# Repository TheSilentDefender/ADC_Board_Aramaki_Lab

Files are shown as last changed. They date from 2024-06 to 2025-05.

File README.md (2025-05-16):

# ADC Hub for pGRAMS
- Has 48 ADC channels and an optional voltage divider can be used for RTDs.
- The ADCs only support a range of 0-5V. Any input outside the range may damage the ADCs on board.
- The board outputs ADC integer values with a 12-bit resolution(0-4095)

## How to build
- Install platform.io on Visual Studio Code. You can also install it manually by following the documenation on [the website](https://platformio.org).
- Open the folder using VSC and wait for platform.io to initialize
- Open the platform.io side panel and click build. This should automatically build with the settings in the configuation file.

## How to flash
- Connect to the board in DFU mode or enter in "d" through serial (press the button on the top while you plug in the board)
- Assuming you followed the instuctions for building, you can click on build and upload which will automatic flash the board and restart it.
- If not you can download the bin file and flash it using dfu-util or any other DFU upgrade tool. For example, `sudo dfu-util -a 0 -i 0 -s 0x08000000:leave -D firmware.bin`.

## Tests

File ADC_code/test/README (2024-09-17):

        
This directory is intended for PlatformIO Test Runner and project tests.

Unit Testing is a software testing method by which individual units of
source code, sets of one or more MCU program modules together with associated
control data, usage procedures, and operating procedures, are tested to
determine whether they are fit for use. Unit testing finds problems early
in the development cycle.

More information about PlatformIO Unit Testing:
- https://docs.platformio.org/en/latest/advanced/unit-testing/index.html

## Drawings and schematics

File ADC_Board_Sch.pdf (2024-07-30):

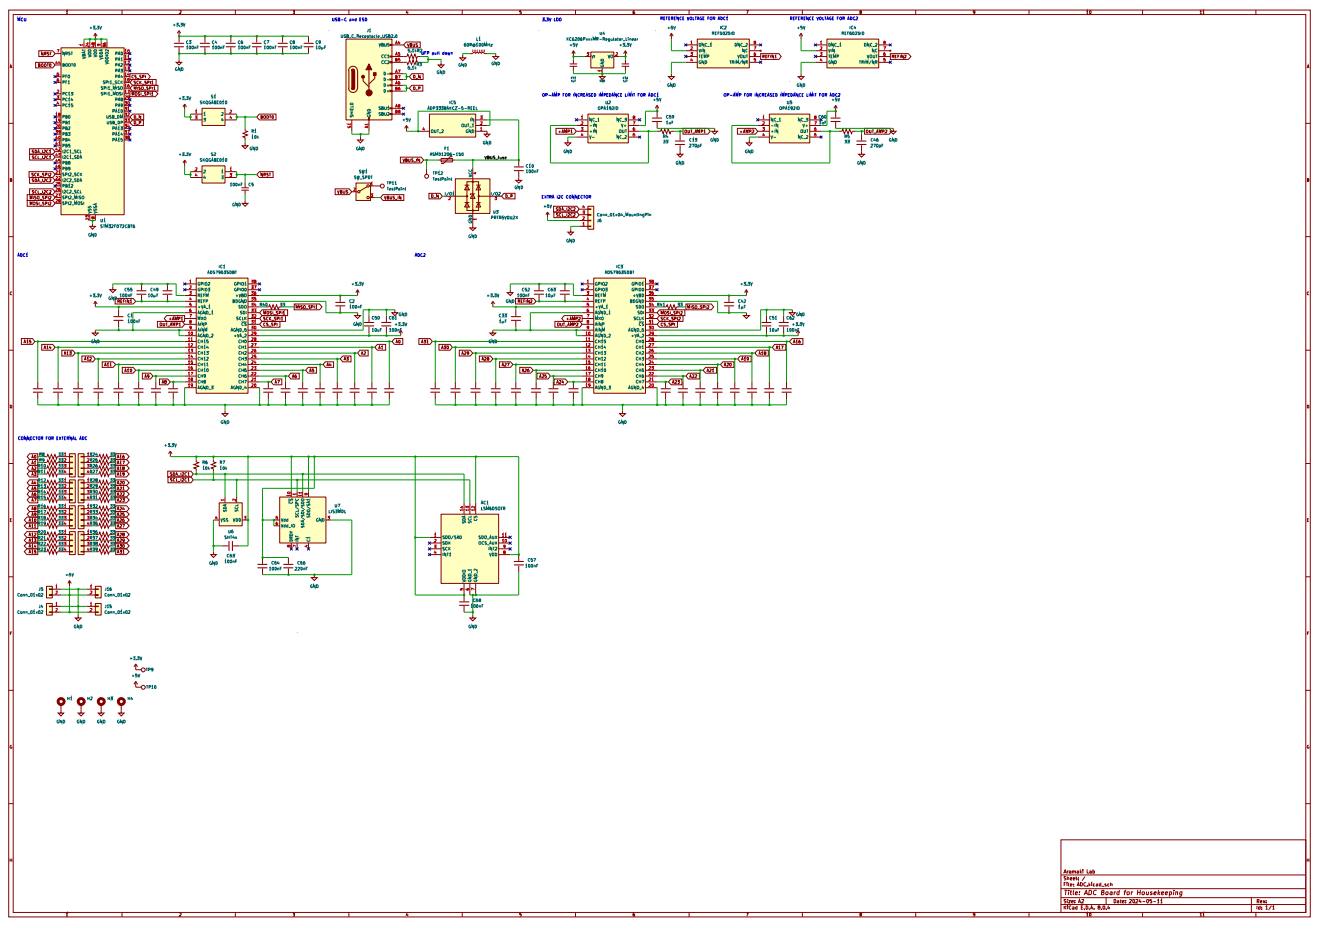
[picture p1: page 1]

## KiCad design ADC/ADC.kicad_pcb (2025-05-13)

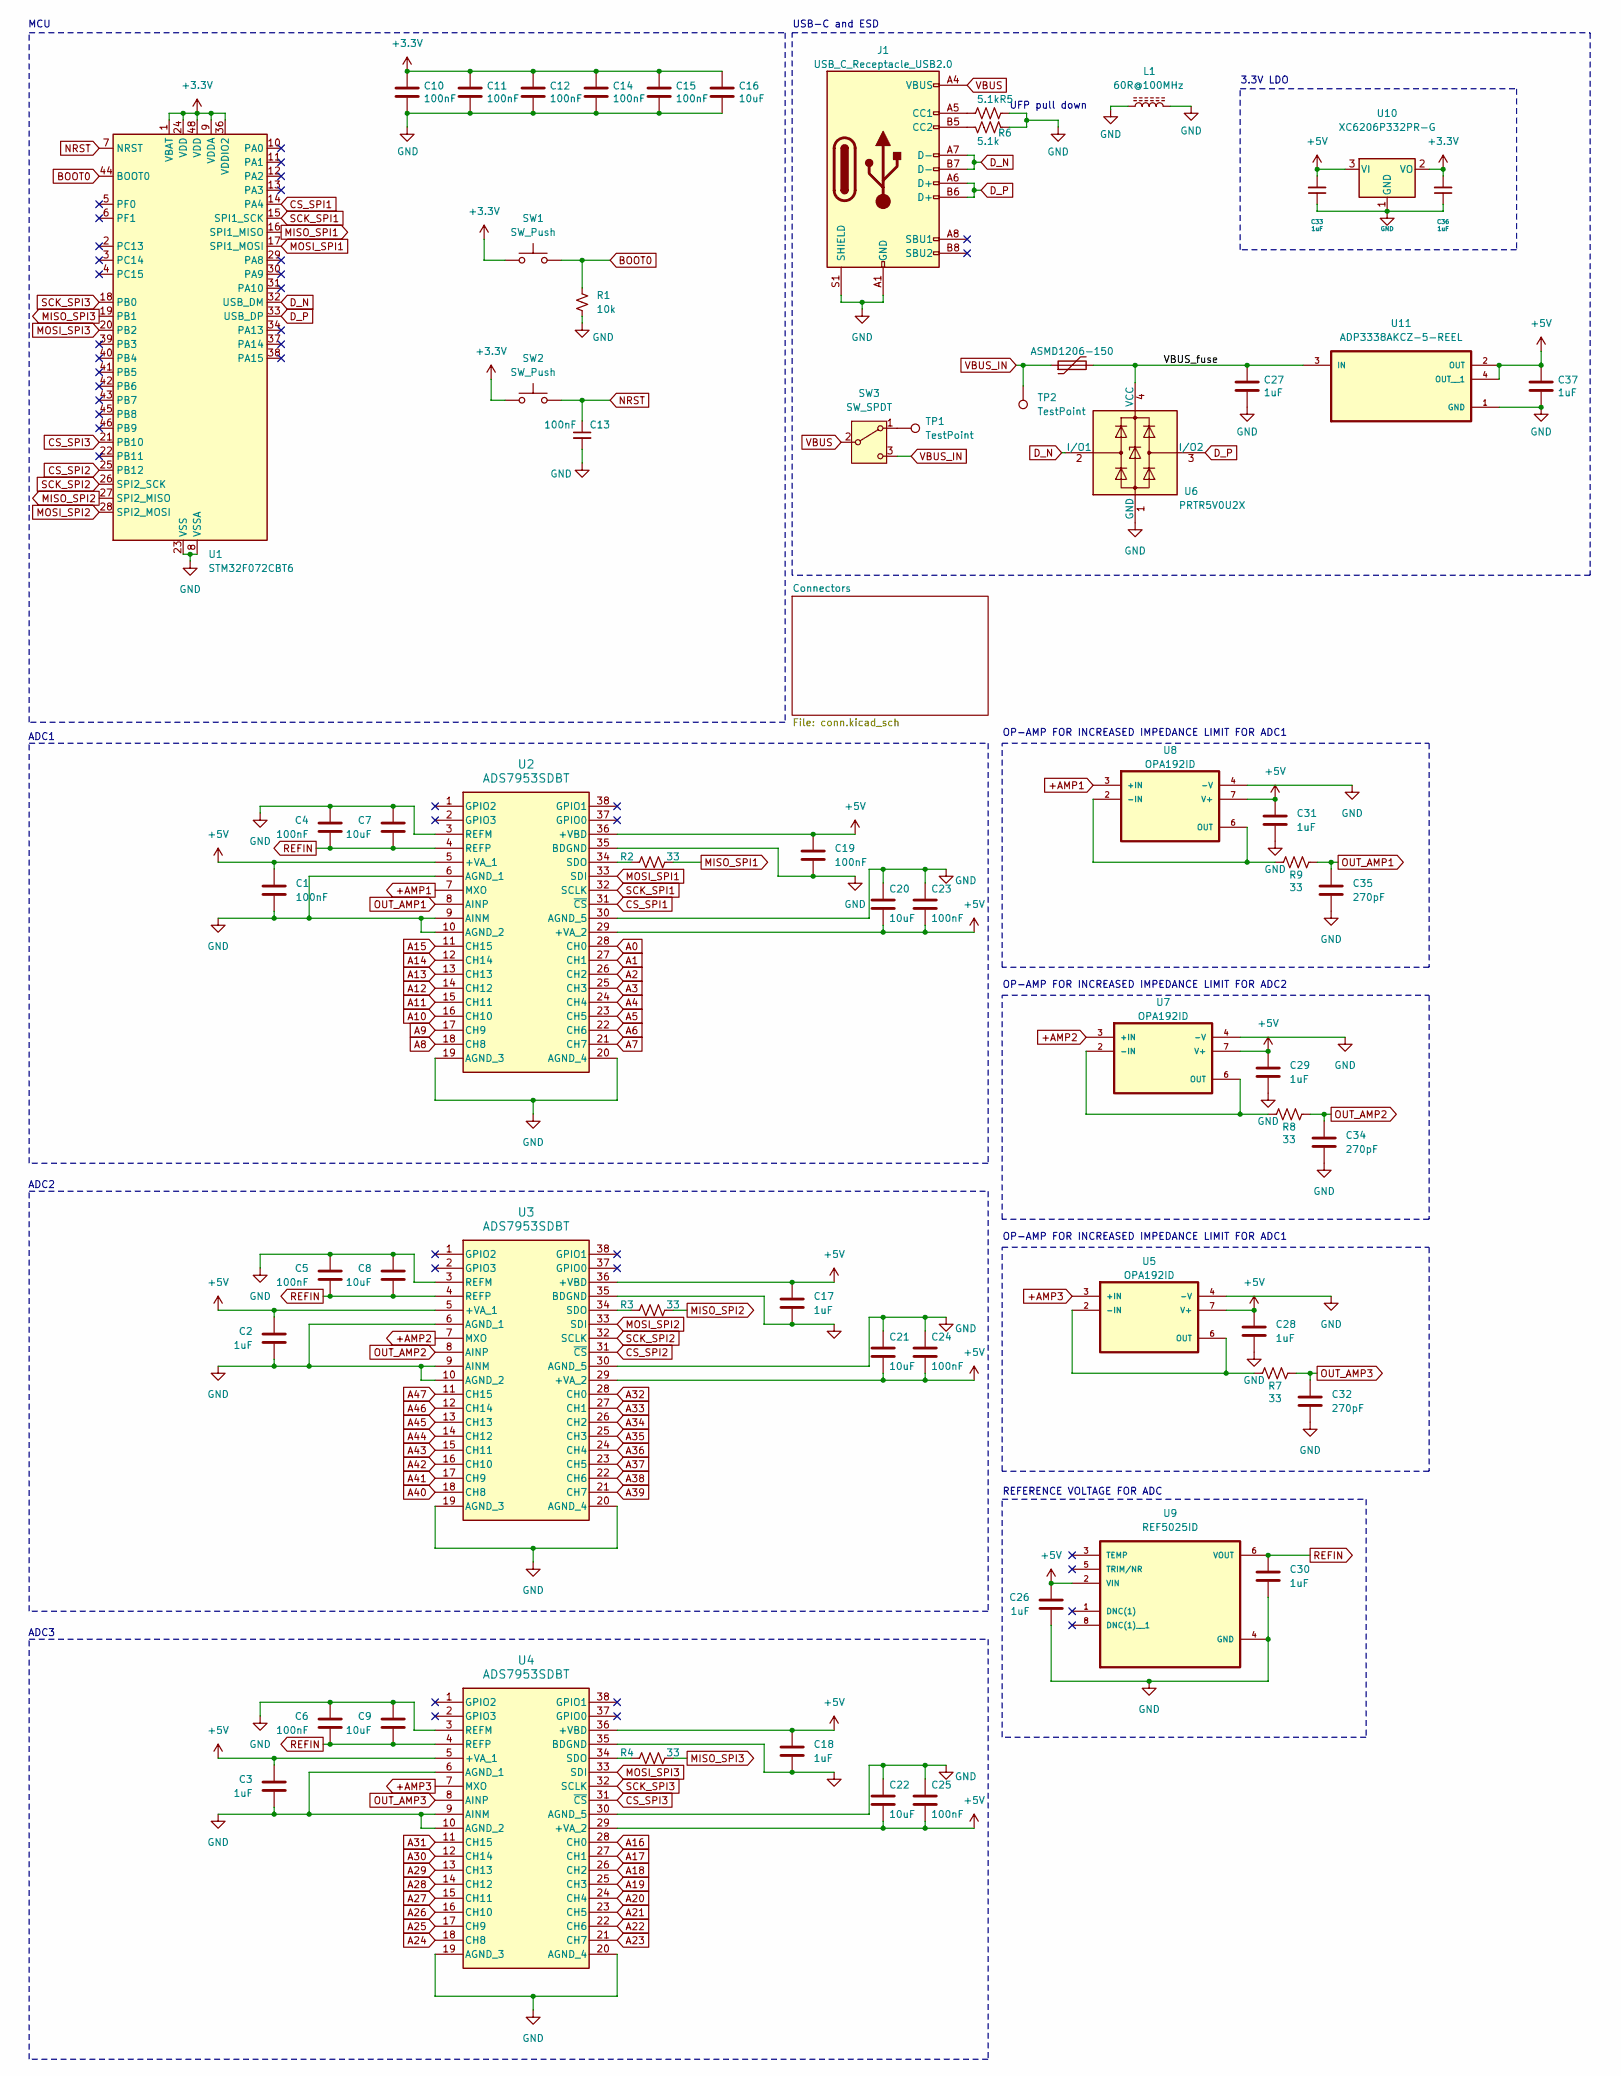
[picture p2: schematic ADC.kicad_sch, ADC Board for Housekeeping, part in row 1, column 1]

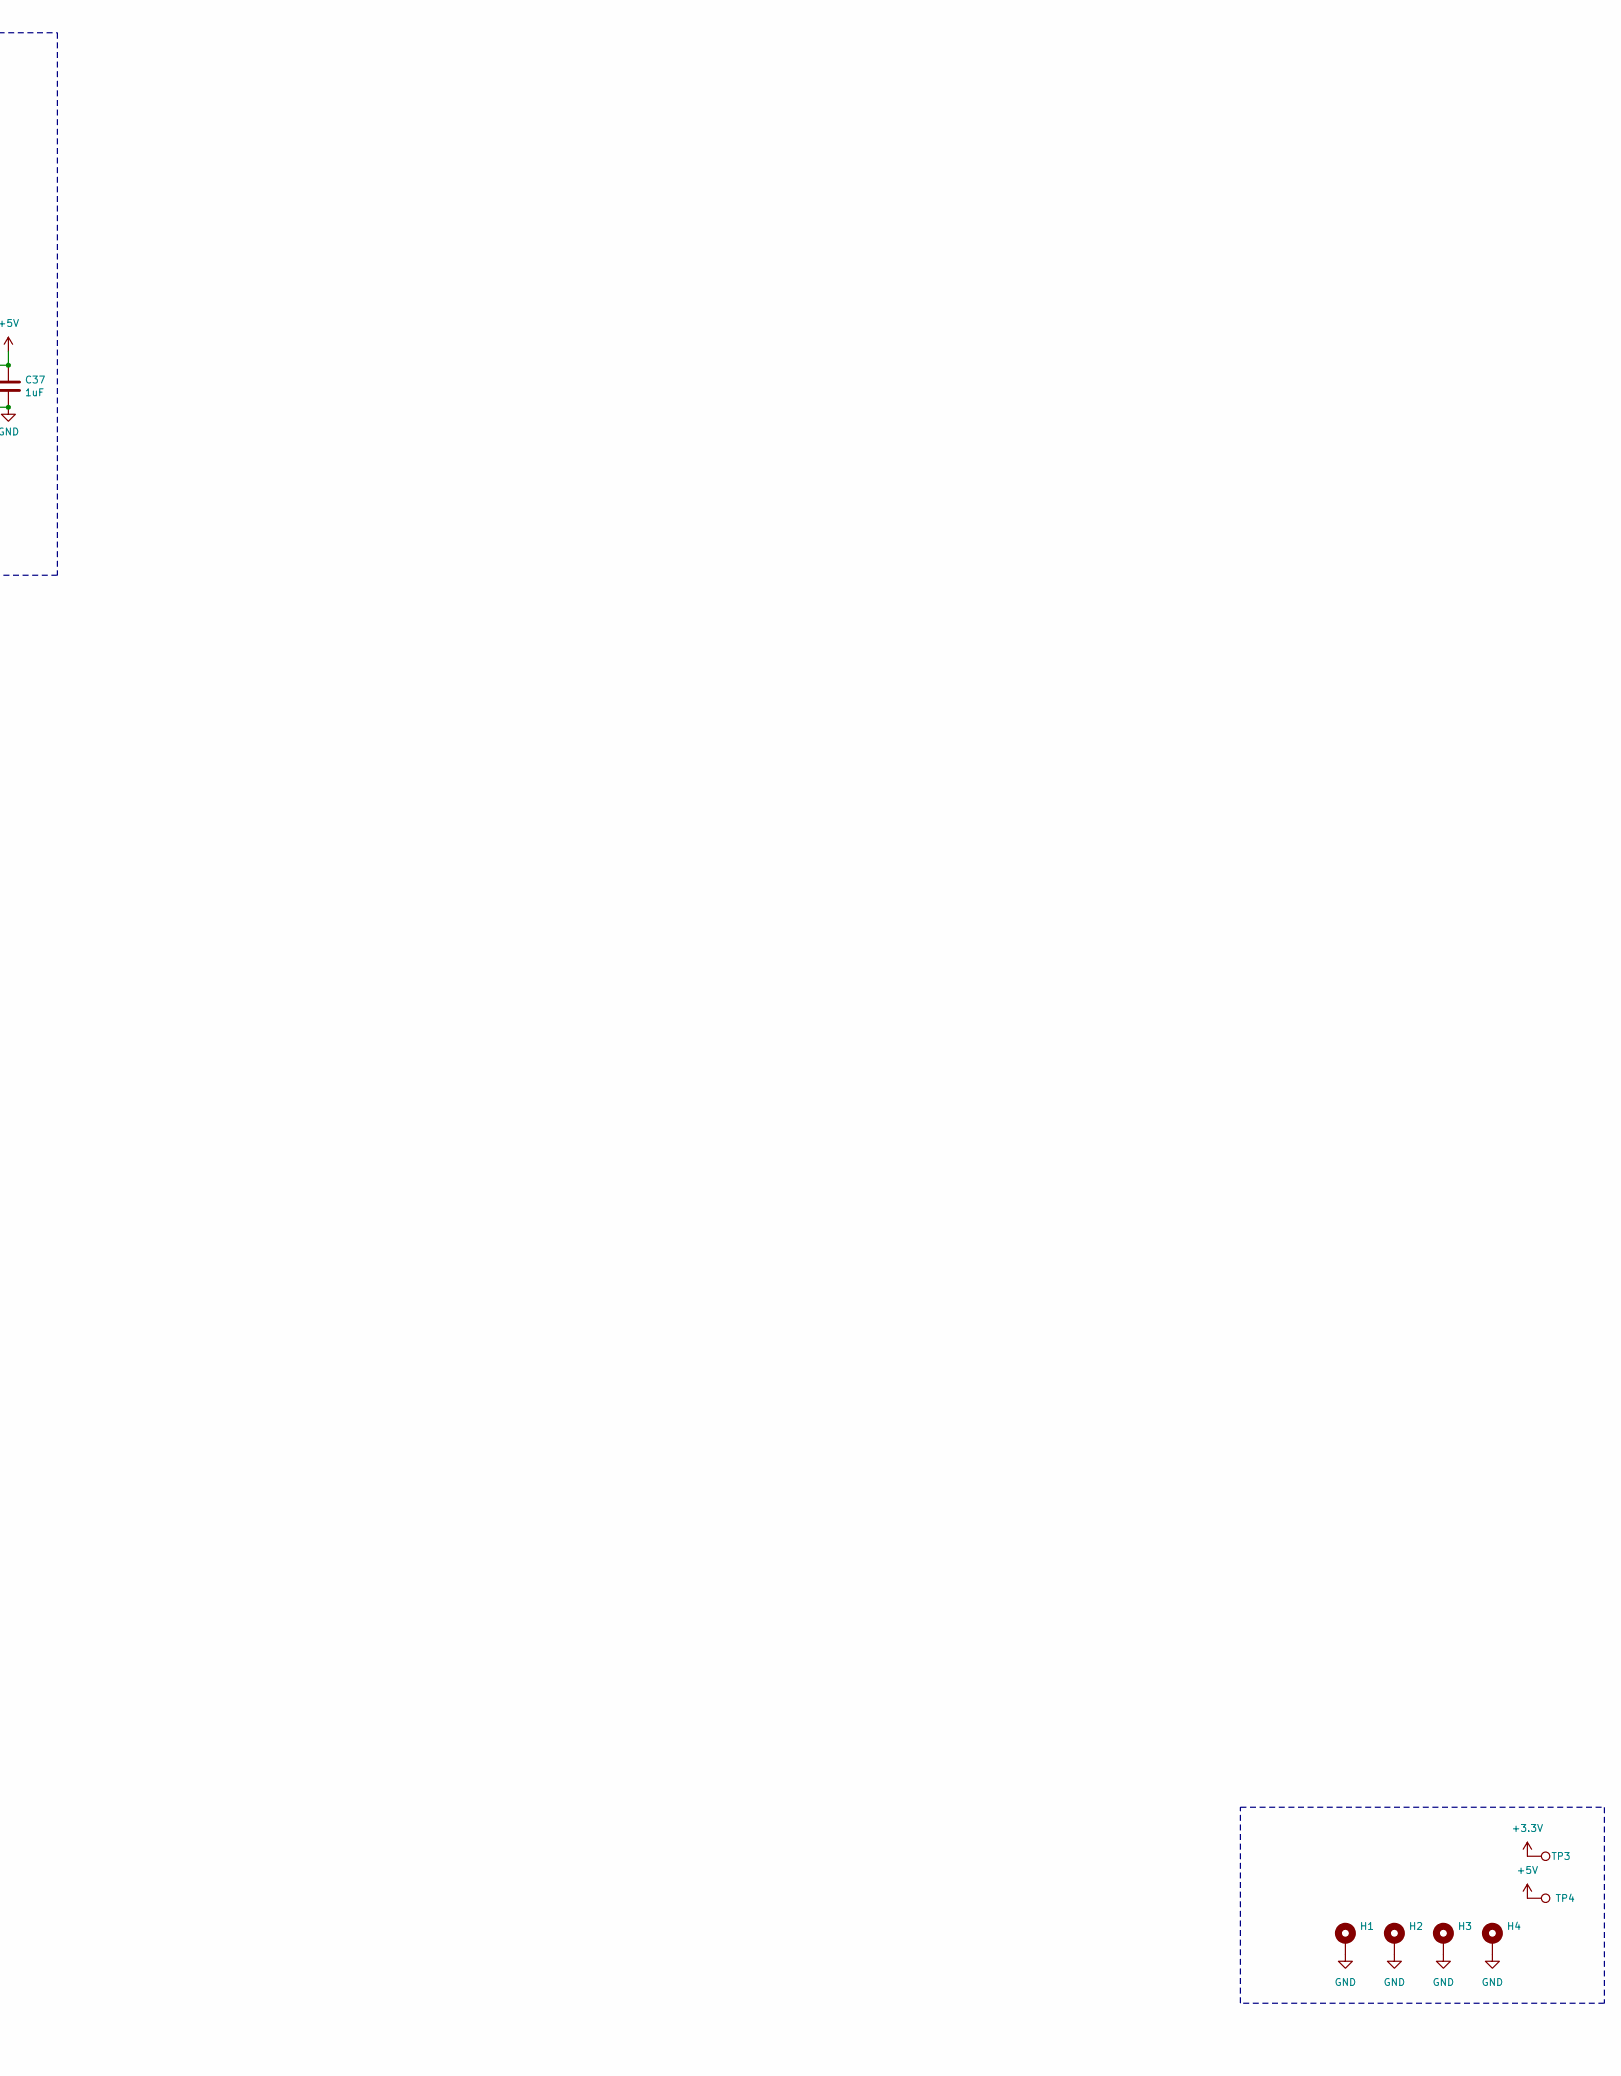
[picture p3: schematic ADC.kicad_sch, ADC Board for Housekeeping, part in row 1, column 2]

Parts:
C1, C4, C5, C6, C19, C23, C24, C25: 100nF; C_0402_1005Metric
C2, C3, C17, C18, C26, C28, C29, C30, C31: 1uF; C_0402_1005Metric
C7, C8, C9, C16, C20, C21, C22: 10uF; C_0402_1005Metric
C10, C11, C12, C13, C14, C15: 100nF; C_0402_1005Metric; LCSC C307331
C27, C37: 1uF; C_0402_1005Metric; LCSC C307331
C32, C34, C35: 270pF; C_0402_1005Metric
C33, C36: 1uF; C_0402_1005Metric; LCSC C52923
F1: ASMD1206-150; Fuse_1206_3216Metric; LCSC C135341
H1, H2, H3, H4: MountingHole_Pad; MountingHole_3mm_Pad
J1: USB_C_Receptacle_USB2.0; USB_C_Receptacle_HRO_TYPE-C-31-M-12; JlcRotOffset 180
L1: 60R@100MHz; L_1206_3216Metric; Manufacturer Part No MLB3216-600P4A(f); LCSC C33600
R1: 10k; R_0402_1005Metric_Pad0.72x0.64mm_HandSolder
R2, R3, R4, R7, R8, R9: 33; R_0402_1005Metric_Pad0.72x0.64mm_HandSolder
R5, R6: 5.1k; R_0402_1005Metric_Pad0.72x0.64mm_HandSolder
SW1, SW2: SW_Push; SW_Push_SPST_NO_Alps_SKRK
SW3: SW_SPDT; SW_SPDT_CK_JS102011SAQN
TP1, TP2, TP3, TP4: TestPoint; TestPoint_Pad_D1.0mm
U1: STM32F072CBT6; LQFP-48_7x7mm_P0.5mm; JlcRotOffset 90
U2, U3, U4: ADS7953SDBT; DBT38
U5, U7, U8: OPA192ID; SOIC127P599X175-8N
U6: PRTR5V0U2X; SOT-143; LCSC C2827688
U9: REF5025ID; SOIC127P599X175-8N
U10: XC6206P332PR-G; SOT-23; LCSC C5446
U11: ADP3338AKCZ-5-REEL; SOT230P700X180-4N

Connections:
+3.3V: C10.1, C11.1, C12.1, C14.1, C15.1, C16.1, C36.2, SW1.1, SW2.1, TP3.1, U1.1 (VBAT), U1.9 (VDDA), U1.24 (VDD), U1.36 (VDDIO2), U1.48 (VDD), U10.2 (VO); also elsewhere on the board
+5V: C1.1, C2.1, C3.1, C17.1, C18.1, C19.1, C20.2, C21.2, C22.2, C23.2, C24.2, C25.2, C26.1, C28.1, C29.1, C31.1, C33.2, C37.1, TP4.1, U2.5 (+VA_1), U2.29 (+VA_2), U2.36 (+VBD), U3.5 (+VA_1), U3.29 (+VA_2), U3.36 (+VBD), U4.5 (+VA_1), U4.29 (+VA_2), U4.36 (+VBD), U5.7 (V+), U7.7 (V+), U8.7 (V+), U9.2 (VIN), U10.3 (VI), U11.2 (OUT), U11.4 (OUT__1); also elsewhere on the board
+AMP1: U2.7 (MXO), U8.3 (+IN)
+AMP2: U3.7 (MXO), U7.3 (+IN)
+AMP3: U4.7 (MXO), U5.3 (+IN)
/VBUS_fuse: C27.1, F1.2, U6.4 (VCC), U11.3 (IN)
A0: U2.28 (CH0); also elsewhere on the board
A1: U2.27 (CH1); also elsewhere on the board
A2: U2.26 (CH2); also elsewhere on the board
A3: U2.25 (CH3); also elsewhere on the board
A4: U2.24 (CH4); also elsewhere on the board
A5: U2.23 (CH5); also elsewhere on the board
A6: U2.22 (CH6); also elsewhere on the board
A7: U2.21 (CH7); also elsewhere on the board
A8: U2.18 (CH8); also elsewhere on the board
A9: U2.17 (CH9); also elsewhere on the board
A10: U2.16 (CH10); also elsewhere on the board
A11: U2.15 (CH11); also elsewhere on the board
A12: U2.14 (CH12); also elsewhere on the board
A13: U2.13 (CH13); also elsewhere on the board
A14: U2.12 (CH14); also elsewhere on the board
A15: U2.11 (CH15); also elsewhere on the board
A16: U4.28 (CH0); also elsewhere on the board
A17: U4.27 (CH1); also elsewhere on the board
A18: U4.26 (CH2); also elsewhere on the board
A19: U4.25 (CH3); also elsewhere on the board
A20: U4.24 (CH4); also elsewhere on the board
A21: U4.23 (CH5); also elsewhere on the board
A22: U4.22 (CH6); also elsewhere on the board
A23: U4.21 (CH7); also elsewhere on the board
A24: U4.18 (CH8); also elsewhere on the board
A25: U4.17 (CH9); also elsewhere on the board
A26: U4.16 (CH10); also elsewhere on the board
A27: U4.15 (CH11); also elsewhere on the board
A28: U4.14 (CH12); also elsewhere on the board
A29: U4.13 (CH13); also elsewhere on the board
A30: U4.12 (CH14); also elsewhere on the board
A31: U4.11 (CH15); also elsewhere on the board
A32: U3.28 (CH0); also elsewhere on the board
A33: U3.27 (CH1); also elsewhere on the board
A34: U3.26 (CH2); also elsewhere on the board
A35: U3.25 (CH3); also elsewhere on the board
A36: U3.24 (CH4); also elsewhere on the board
A37: U3.23 (CH5); also elsewhere on the board
A38: U3.22 (CH6); also elsewhere on the board
A39: U3.21 (CH7); also elsewhere on the board
A40: U3.18 (CH8); also elsewhere on the board
A41: U3.17 (CH9); also elsewhere on the board
A42: U3.16 (CH10); also elsewhere on the board
A43: U3.15 (CH11); also elsewhere on the board
A44: U3.14 (CH12); also elsewhere on the board
A45: U3.13 (CH13); also elsewhere on the board
A46: U3.12 (CH14); also elsewhere on the board
A47: U3.11 (CH15); also elsewhere on the board
BOOT0: R1.1, SW1.2, U1.44 (BOOT0)
CS_SPI1: U1.14 (PA4), U2.31 (~CS)
CS_SPI2: U1.25 (PB12), U3.31 (~CS)
CS_SPI3: U1.21 (PB10), U4.31 (~CS)
D_N: J1.A7 (D-), J1.B7 (D-), U1.32 (USB_DM), U6.2 (I/O1)
D_P: J1.A6 (D+), J1.B6 (D+), U1.33 (USB_DP), U6.3 (I/O2)
GND: C1.2, C2.2, C3.2, C4.1, C5.1, C6.1, C7.1, C8.1, C9.1, C10.2, C11.2, C12.2, C13.2, C14.2, C15.2, C16.2, C17.2, C18.2, C19.2, C20.1, C21.1, C22.1, C23.1, C24.1, C25.1, C26.2, C27.2, C28.2, C29.2, C30.2, C31.2, C32.2, C33.1, C34.2, C35.2, C36.1, C37.2, H1.1, H2.1, H3.1, H4.1, J1.A1 (GND), J1.A12 (GND), J1.B1 (GND), J1.B12 (GND), J1.S1 (SHIELD), L1.1, L1.2, R1.2, R5.1, R6.1, U1.8 (VSSA), U1.23 (VSS), U1.35 (VSS), U1.47 (VSS), U2.3 (REFM), U2.6 (AGND_1), U2.9 (AINM), U2.10 (AGND_2), U2.19 (AGND_3), U2.20 (AGND_4), U2.30 (AGND_5), U2.35 (BDGND), U3.3 (REFM), U3.6 (AGND_1), U3.9 (AINM), U3.10 (AGND_2), U3.19 (AGND_3), U3.20 (AGND_4), U3.30 (AGND_5), U3.35 (BDGND), U4.3 (REFM), U4.6 (AGND_1), U4.9 (AINM), U4.10 (AGND_2), U4.19 (AGND_3), U4.20 (AGND_4), U4.30 (AGND_5), U4.35 (BDGND), U5.4 (-V), U6.1 (GND), U7.4 (-V), U8.4 (-V), U9.4 (GND), U10.1 (GND), U11.1 (GND); also elsewhere on the board
MISO_SPI1: R2.2, U1.16 (SPI1_MISO)
MISO_SPI2: R3.2, U1.27 (SPI2_MISO)
MISO_SPI3: R4.2, U1.19 (PB1)
MOSI_SPI1: U1.17 (SPI1_MOSI), U2.33 (SDI)
MOSI_SPI2: U1.28 (SPI2_MOSI), U3.33 (SDI)
MOSI_SPI3: U1.20 (PB2), U4.33 (SDI)
NRST: C13.1, SW2.2, U1.7 (NRST)
unnamed: J1.A5 (CC1), R5.2
unnamed: J1.B5 (CC2), R6.2
unnamed: SW3.1 (A), TP1.1
unnamed: R2.1, U2.34 (SDO)
unnamed: R3.1, U3.34 (SDO)
unnamed: R4.1, U4.34 (SDO)
unnamed: R7.1, U5.2 (-IN), U5.6 (OUT)
unnamed: R8.1, U7.2 (-IN), U7.6 (OUT)
unnamed: R9.1, U8.2 (-IN), U8.6 (OUT)
OUT_AMP1: C35.1, R9.2, U2.8 (AINP)
OUT_AMP2: C34.1, R8.2, U3.8 (AINP)
OUT_AMP3: C32.1, R7.2, U4.8 (AINP)
REFIN: C4.2, C5.2, C6.2, C7.2, C8.2, C9.2, C30.1, U2.4 (REFP), U3.4 (REFP), U4.4 (REFP), U9.6 (VOUT)
SCK_SPI1: U1.15 (SPI1_SCK), U2.32 (SCLK)
SCK_SPI2: U1.26 (SPI2_SCK), U3.32 (SCLK)
SCK_SPI3: U1.18 (PB0), U4.32 (SCLK)
VBUS: J1.A4 (VBUS), J1.A9 (VBUS), J1.B4 (VBUS), J1.B9 (VBUS), SW3.2 (B)
VBUS_IN: F1.1, SW3.3 (C), TP2.1

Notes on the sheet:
OP-AMP FOR INCREASED IMPEDANCE LIMIT FOR ADC1
MCU
OP-AMP FOR INCREASED IMPEDANCE LIMIT FOR ADC2
UFP pull down
ADC1
REFERENCE VOLTAGE FOR ADC
ADC3
3.3V LDO
USB-C and ESD
ADC2

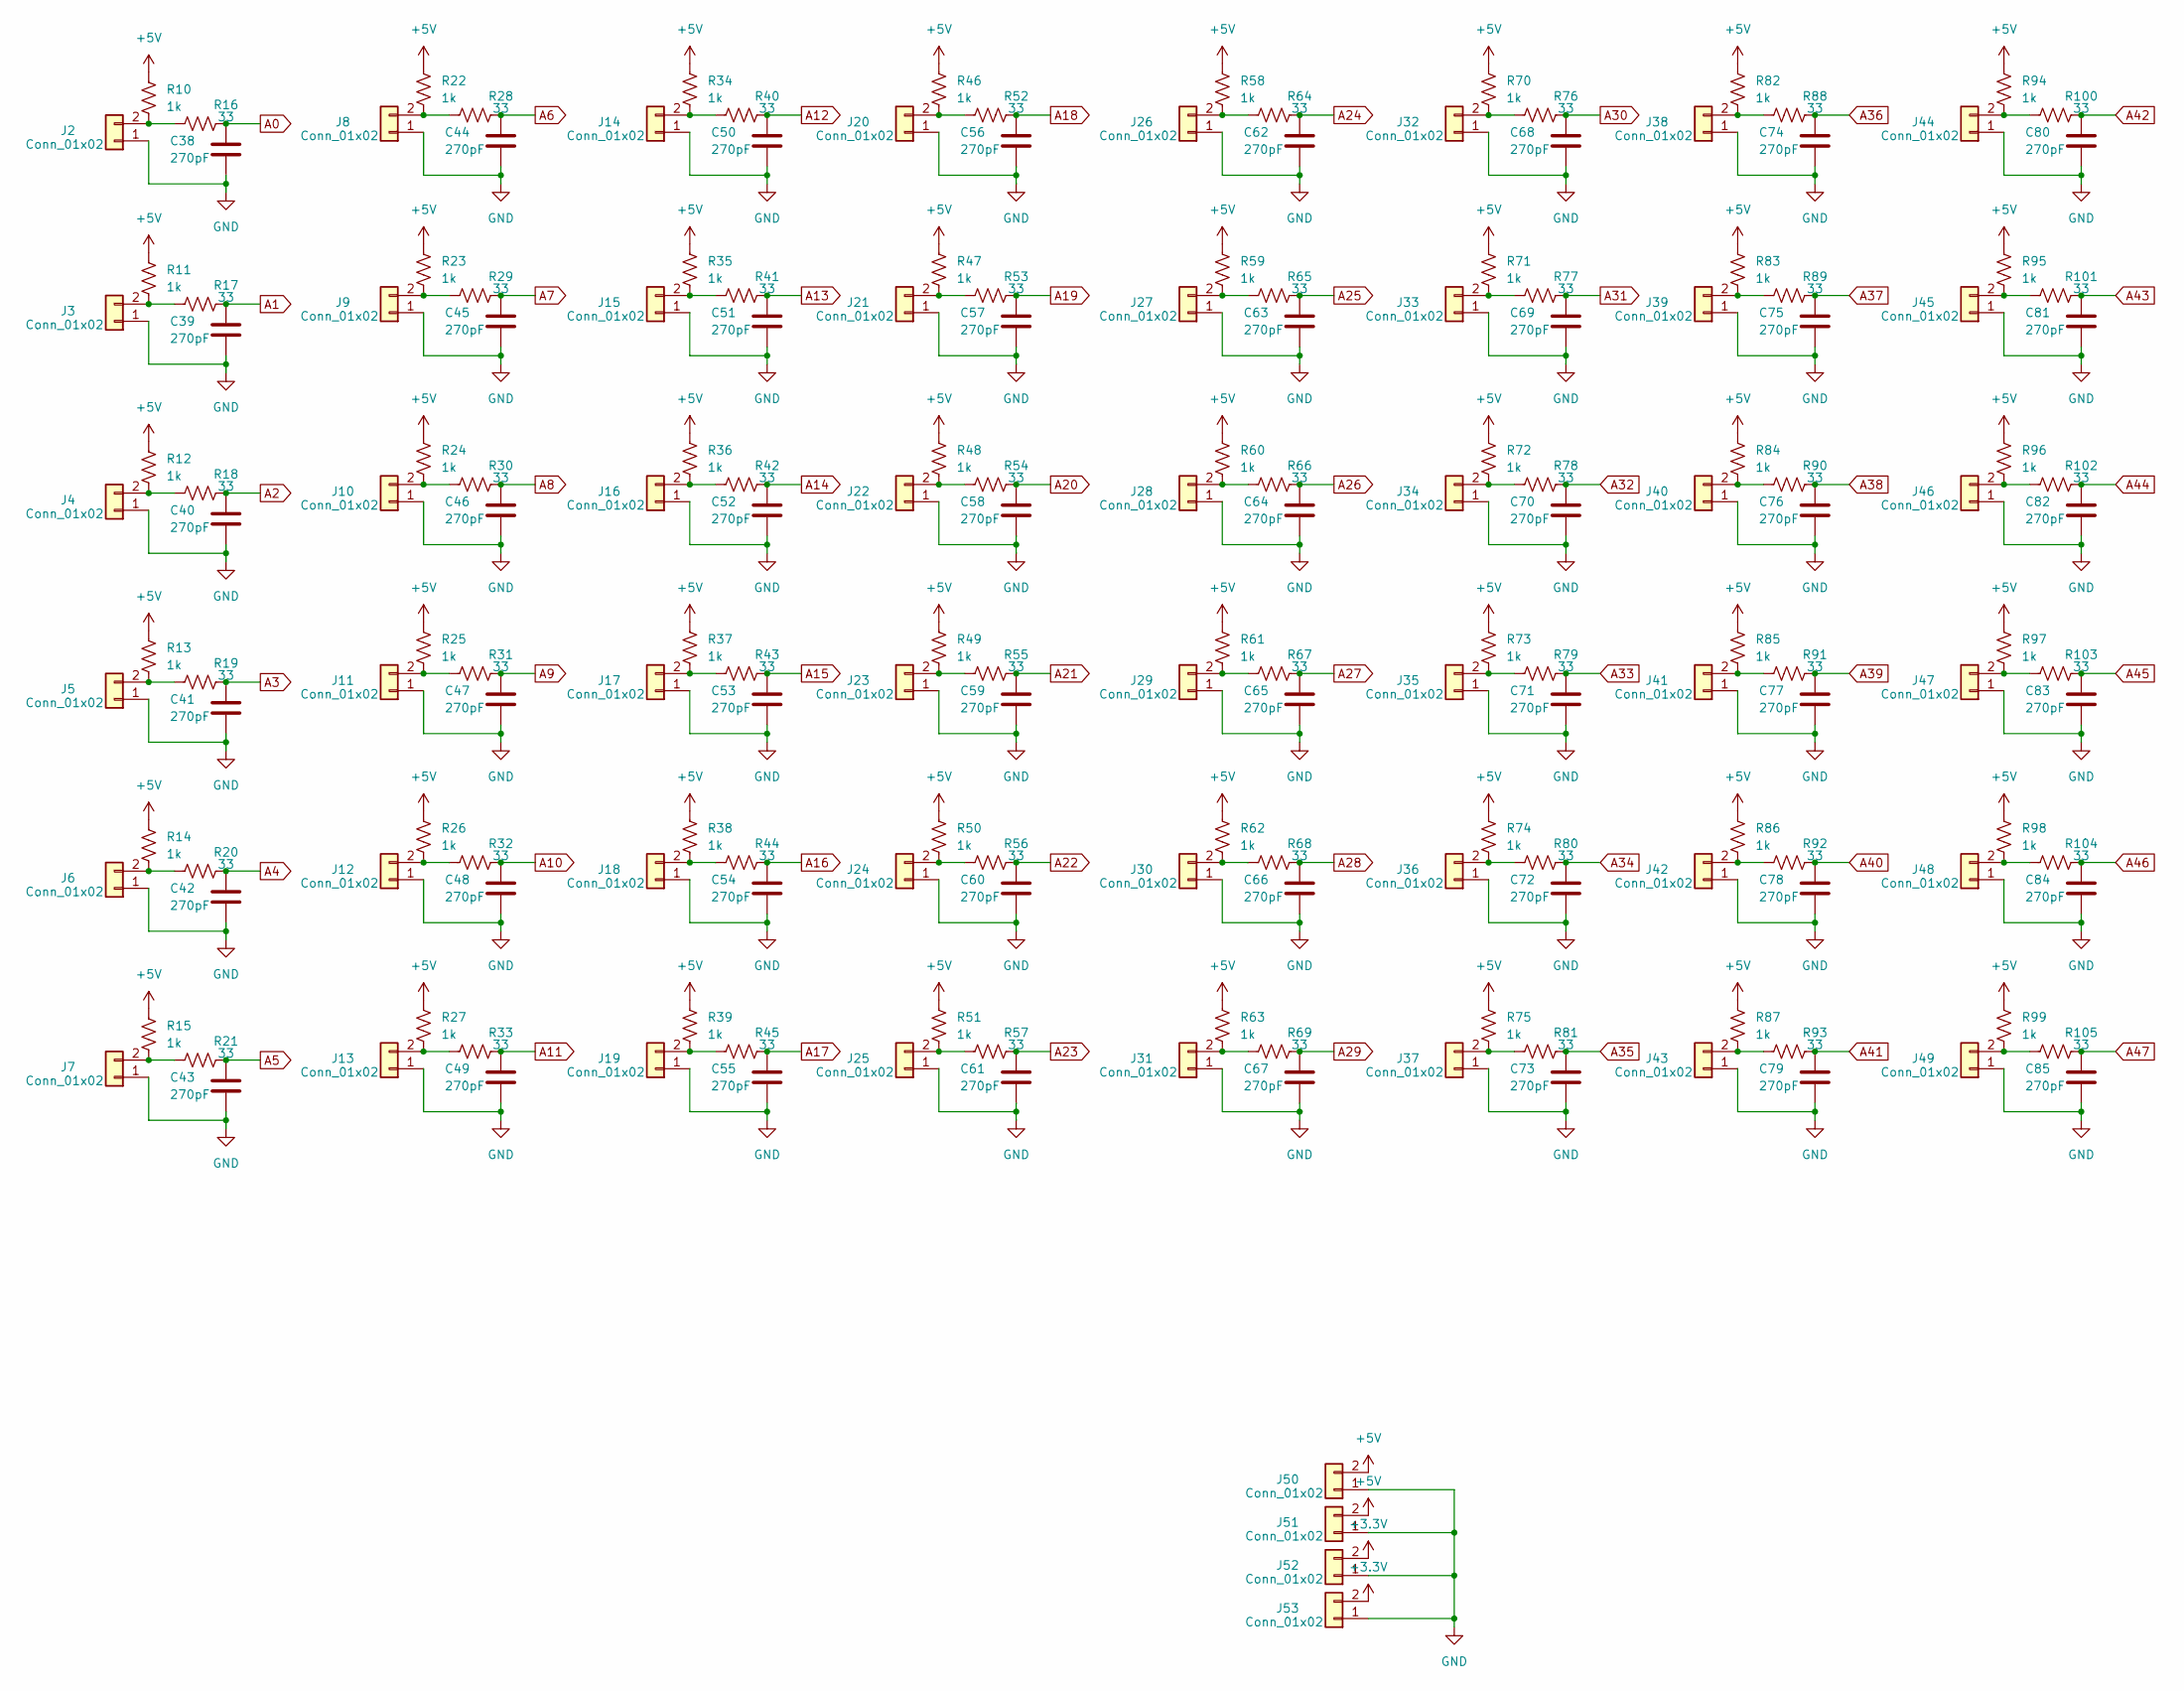
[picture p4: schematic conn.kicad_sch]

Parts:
C38, C39, C40, C41, C42, C43, C44, C45, C46, C47, C48, C49, C50, C51, C52, C53, C54, C55, C56, C57, C58, C59, C60, C61, C62, C63, C64, C65, C66, C67, C68, C69, C70, C71, C72, C73, C74, C75, C76, C77, C78, C79, C80, C81, C82, C83, C84, C85: 270pF; C_0402_1005Metric
J2, J3, J4, J5, J6, J7, J8, J9, J10, J11, J12, J13, J14, J15, J16, J17, J18, J19, J20, J21, J22, J23, J24, J25, J26, J27, J28, J29, J30, J31, J32, J33, J34, J35, J36, J37, J38, J39, J40, J41, J42, J43, J44, J45, J46, J47, J48, J49: Conn_01x02; Molex_Mini-Fit_Jr_5566-02A_2x01_P4.20mm_Vertical
J50, J51, J52, J53: Conn_01x02; PinHeader_1x02_P2.54mm_Vertical
R10, R11, R12, R13, R14, R15, R22, R23, R24, R25, R26, R27, R34, R35, R36, R37, R38, R39, R46, R47, R48, R49, R50, R51, R58, R59, R60, R61, R62, R63, R70, R71, R72, R73, R74, R75, R82, R83, R84, R85, R86, R87, R94, R95, R96, R97, R98, R99: 1k; R_0603_1608Metric_Pad0.98x0.95mm_HandSolder
R16, R17, R18, R19, R20, R21, R28, R29, R30, R31, R32, R33, R40, R41, R42, R43, R44, R45, R52, R53, R54, R55, R56, R57, R64, R65, R66, R67, R68, R69, R76, R77, R78, R79, R80, R81, R88, R89, R90, R91, R92, R93, R100, R101, R102, R103, R104, R105: 33; R_0402_1005Metric_Pad0.72x0.64mm_HandSolder

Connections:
+3.3V: J52.2, J53.2; also elsewhere on the board
+5V: J50.2, J51.2, R10.1, R11.1, R12.1, R13.1, R14.1, R15.1, R22.1, R23.1, R24.1, R25.1, R26.1, R27.1, R34.1, R35.1, R36.1, R37.1, R38.1, R39.1, R46.1, R47.1, R48.1, R49.1, R50.1, R51.1, R58.1, R59.1, R60.1, R61.1, R62.1, R63.1, R70.1, R71.1, R72.1, R73.1, R74.1, R75.1, R82.1, R83.1, R84.1, R85.1, R86.1, R87.1, R94.1, R95.1, R96.1, R97.1, R98.1, R99.1; also elsewhere on the board
A0: C38.1, R16.2; also elsewhere on the board
A1: C39.1, R17.2; also elsewhere on the board
A2: C40.1, R18.2; also elsewhere on the board
A3: C41.1, R19.2; also elsewhere on the board
A4: C42.1, R20.2; also elsewhere on the board
A5: C43.1, R21.2; also elsewhere on the board
A6: C44.1, R28.2; also elsewhere on the board
A7: C45.1, R29.2; also elsewhere on the board
A8: C46.1, R30.2; also elsewhere on the board
A9: C47.1, R31.2; also elsewhere on the board
A10: C48.1, R32.2; also elsewhere on the board
A11: C49.1, R33.2; also elsewhere on the board
A12: C50.1, R40.2; also elsewhere on the board
A13: C51.1, R41.2; also elsewhere on the board
A14: C52.1, R42.2; also elsewhere on the board
A15: C53.1, R43.2; also elsewhere on the board
A16: C54.1, R44.2; also elsewhere on the board
A17: C55.1, R45.2; also elsewhere on the board
A18: C56.1, R52.2; also elsewhere on the board
A19: C57.1, R53.2; also elsewhere on the board
A20: C58.1, R54.2; also elsewhere on the board
A21: C59.1, R55.2; also elsewhere on the board
A22: C60.1, R56.2; also elsewhere on the board
A23: C61.1, R57.2; also elsewhere on the board
A24: C62.1, R64.2; also elsewhere on the board
A25: C63.1, R65.2; also elsewhere on the board
A26: C64.1, R66.2; also elsewhere on the board
A27: C65.1, R67.2; also elsewhere on the board
A28: C66.1, R68.2; also elsewhere on the board
A29: C67.1, R69.2; also elsewhere on the board
A30: C68.1, R76.2; also elsewhere on the board
A31: C69.1, R77.2; also elsewhere on the board
A32: C70.1, R78.2; also elsewhere on the board
A33: C71.1, R79.2; also elsewhere on the board
A34: C72.1, R80.2; also elsewhere on the board
A35: C73.1, R81.2; also elsewhere on the board
A36: C74.1, R88.2; also elsewhere on the board
A37: C75.1, R89.2; also elsewhere on the board
A38: C76.1, R90.2; also elsewhere on the board
A39: C77.1, R91.2; also elsewhere on the board
A40: C78.1, R92.2; also elsewhere on the board
A41: C79.1, R93.2; also elsewhere on the board
A42: C80.1, R100.2; also elsewhere on the board
A43: C81.1, R101.2; also elsewhere on the board
A44: C82.1, R102.2; also elsewhere on the board
A45: C83.1, R103.2; also elsewhere on the board
A46: C84.1, R104.2; also elsewhere on the board
A47: C85.1, R105.2; also elsewhere on the board
GND: C38.2, C39.2, C40.2, C41.2, C42.2, C43.2, C44.2, C45.2, C46.2, C47.2, C48.2, C49.2, C50.2, C51.2, C52.2, C53.2, C54.2, C55.2, C56.2, C57.2, C58.2, C59.2, C60.2, C61.2, C62.2, C63.2, C64.2, C65.2, C66.2, C67.2, C68.2, C69.2, C70.2, C71.2, C72.2, C73.2, C74.2, C75.2, C76.2, C77.2, C78.2, C79.2, C80.2, C81.2, C82.2, C83.2, C84.2, C85.2, J2.1, J3.1, J4.1, J5.1, J6.1, J7.1, J8.1, J9.1, J10.1, J11.1, J12.1, J13.1, J14.1, J15.1, J16.1, J17.1, J18.1, J19.1, J20.1, J21.1, J22.1, J23.1, J24.1, J25.1, J26.1, J27.1, J28.1, J29.1, J30.1, J31.1, J32.1, J33.1, J34.1, J35.1, J36.1, J37.1, J38.1, J39.1, J40.1, J41.1, J42.1, J43.1, J44.1, J45.1, J46.1, J47.1, J48.1, J49.1, J50.1, J51.1, J52.1, J53.1; also elsewhere on the board
unnamed: J2.2, R10.2, R16.1
unnamed: J3.2, R11.2, R17.1
unnamed: J4.2, R12.2, R18.1
unnamed: J5.2, R13.2, R19.1
unnamed: J6.2, R14.2, R20.1
unnamed: J7.2, R15.2, R21.1
unnamed: J8.2, R22.2, R28.1
unnamed: J9.2, R23.2, R29.1
unnamed: J10.2, R24.2, R30.1
unnamed: J11.2, R25.2, R31.1
unnamed: J12.2, R26.2, R32.1
unnamed: J13.2, R27.2, R33.1
unnamed: J14.2, R34.2, R40.1
unnamed: J15.2, R35.2, R41.1
unnamed: J16.2, R36.2, R42.1
unnamed: J17.2, R37.2, R43.1
unnamed: J18.2, R38.2, R44.1
unnamed: J19.2, R39.2, R45.1
unnamed: J20.2, R46.2, R52.1
unnamed: J21.2, R47.2, R53.1
unnamed: J22.2, R48.2, R54.1
unnamed: J23.2, R49.2, R55.1
unnamed: J24.2, R50.2, R56.1
unnamed: J25.2, R51.2, R57.1
unnamed: J26.2, R58.2, R64.1
unnamed: J27.2, R59.2, R65.1
unnamed: J28.2, R60.2, R66.1
unnamed: J29.2, R61.2, R67.1
unnamed: J30.2, R62.2, R68.1
unnamed: J31.2, R63.2, R69.1
unnamed: J32.2, R70.2, R76.1
unnamed: J33.2, R71.2, R77.1
unnamed: J34.2, R72.2, R78.1
unnamed: J35.2, R73.2, R79.1
unnamed: J36.2, R74.2, R80.1
unnamed: J37.2, R75.2, R81.1
unnamed: J38.2, R82.2, R88.1
unnamed: J39.2, R83.2, R89.1
unnamed: J40.2, R84.2, R90.1
unnamed: J41.2, R85.2, R91.1
unnamed: J42.2, R86.2, R92.1
unnamed: J43.2, R87.2, R93.1
unnamed: J44.2, R94.2, R100.1
unnamed: J45.2, R95.2, R101.1
unnamed: J46.2, R96.2, R102.1
unnamed: J47.2, R97.2, R103.1
unnamed: J48.2, R98.2, R104.1
unnamed: J49.2, R99.2, R105.1

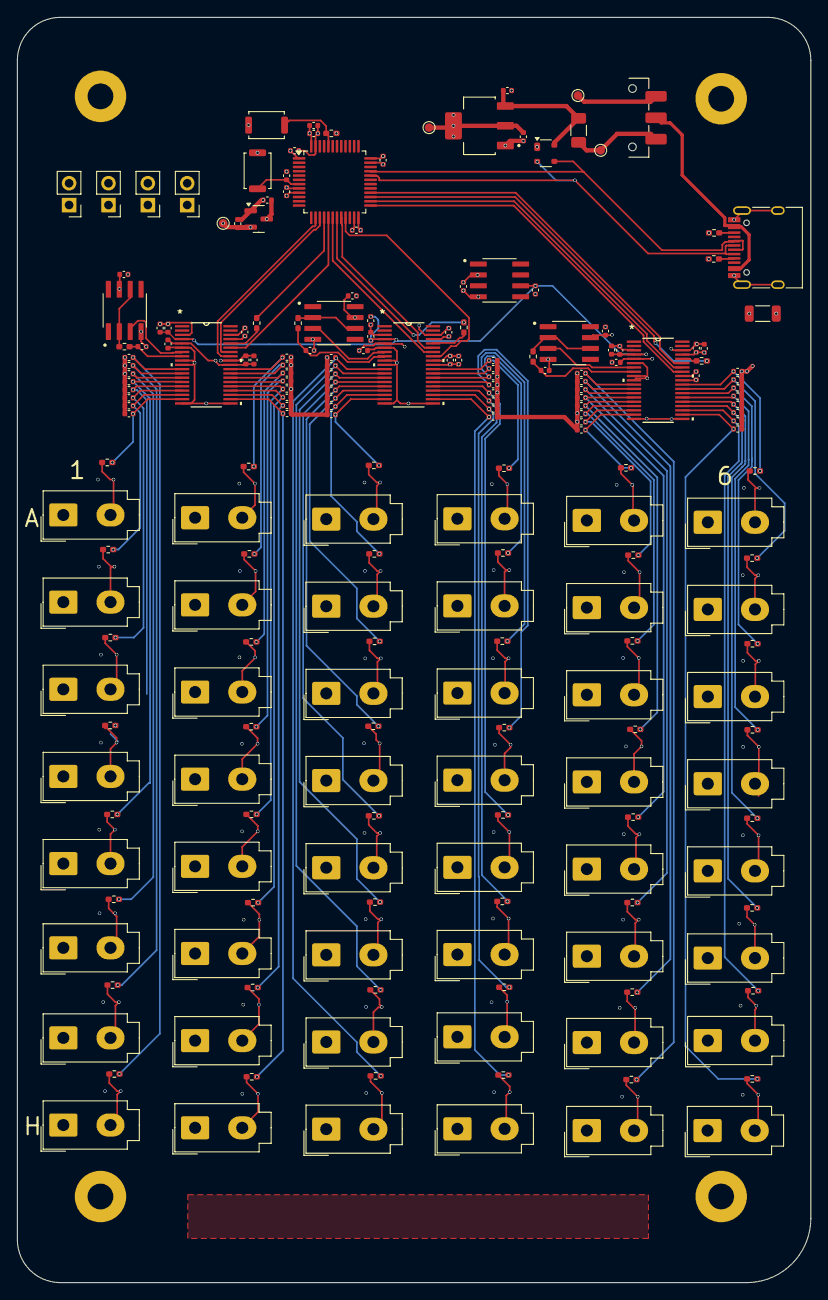
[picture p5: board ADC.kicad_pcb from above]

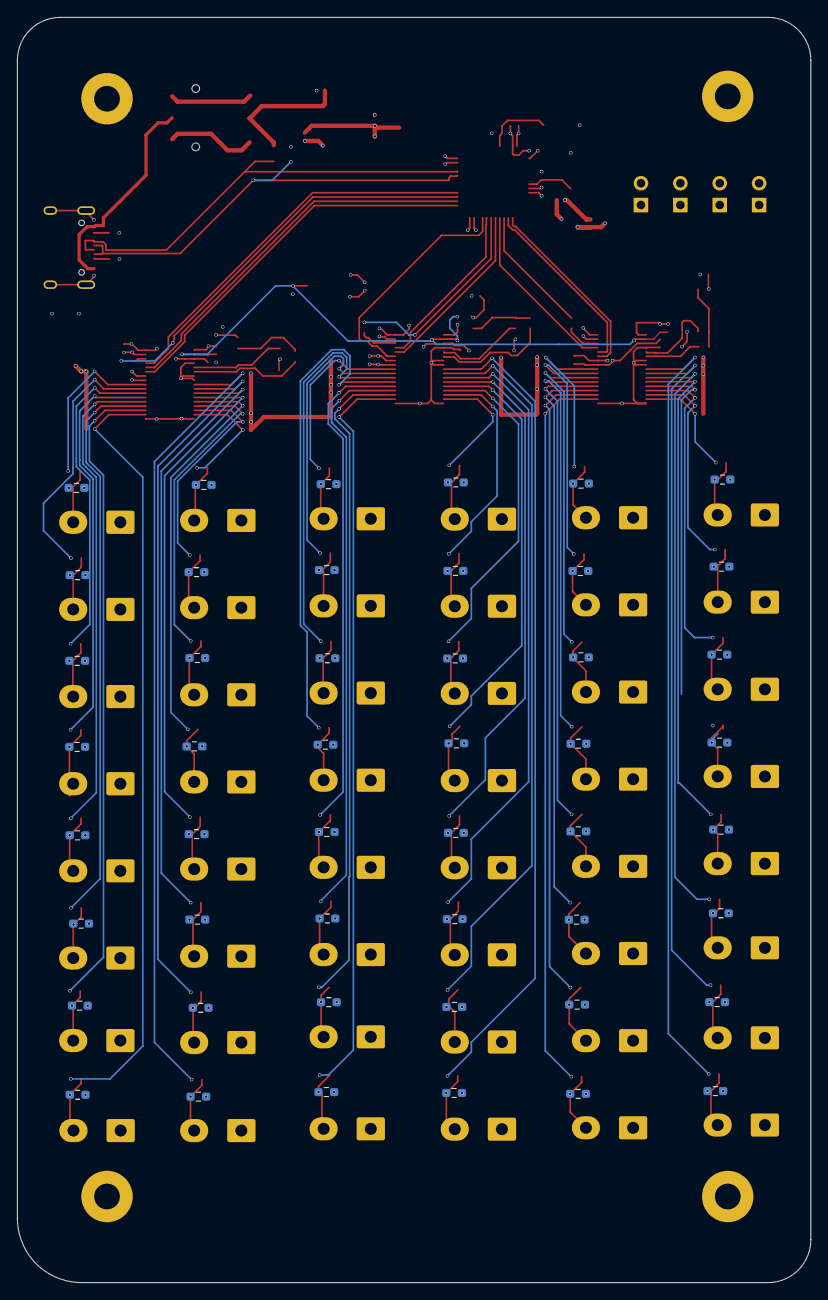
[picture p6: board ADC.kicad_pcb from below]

Board: 4 copper layers, 92.5 x 147.5 mm, 267 parts (48 on the bottom side), 134 nets.

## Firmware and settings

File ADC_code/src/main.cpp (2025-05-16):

#include <SPI.h>
#include <SoftSPI.h>

// Define SPI pins
#define SCK_PIN_ADS7953_1 PA_5
#define MISO_PIN_ADS7953_1 PA_6
#define MOSI_PIN_ADS7953_1 PA_7
#define CS_PIN_ADS7953_1 PA_4

#define SCK_PIN_ADS7953_2 PB_13
#define MISO_PIN_ADS7953_2 PB_14
#define MOSI_PIN_ADS7953_2 PB_15
#define CS_PIN_ADS7953_2 PB_12

#define SCK_PIN_ADS7953_3 PB_0
#define MISO_PIN_ADS7953_3 PB_1
#define MOSI_PIN_ADS7953_3 PB_2
#define CS_PIN_ADS7953_3 PB_10

SPIClass ADS7953_1;
SPIClass ADS7953_2;
SoftSPI ADS7953_3(MOSI_PIN_ADS7953_3, MISO_PIN_ADS7953_3, SCK_PIN_ADS7953_3);

#define CHANNELS_TO_PRINT 48

int sensorData[CHANNELS_TO_PRINT] = {0};
int order[CHANNELS_TO_PRINT] = {8, 9, 10, 11, 12, 13, 14, 15,
                                0, 1, 2, 3, 4, 5, 6, 7,
                                24, 25, 26, 27, 28, 29, 30, 31,
                                16, 17, 18, 19, 20, 21, 22, 23,
                                40, 41, 42, 43, 44, 45, 46, 47,
                                32, 33, 34, 35, 36, 37, 38, 39};

void setupADS7953(SPIClass ADS7953, int cs);
void setupSoftADS7953(SoftSPI ADS7953, int cs);
void readADS7953(SPIClass ADS7953, int adc, int cs);
void readSoftADS7953(SoftSPI ADS7953, int adc, int cs);
void printADC();
void JumpToBootloader();
void reset();

void setup()
{

    // Initialize serial communication for debugging
    Serial.begin(9600);

    pinMode(CS_PIN_ADS7953_1, OUTPUT);
    pinMode(CS_PIN_ADS7953_2, OUTPUT);
    pinMode(CS_PIN_ADS7953_3, OUTPUT);
    digitalWrite(CS_PIN_ADS7953_1, HIGH);
    digitalWrite(CS_PIN_ADS7953_2, HIGH);
    digitalWrite(CS_PIN_ADS7953_3, HIGH);

    ADS7953_1.begin();
    ADS7953_1.setMOSI(MOSI_PIN_ADS7953_1);
    ADS7953_1.setMISO(MISO_PIN_ADS7953_1);
    ADS7953_1.setSCLK(SCK_PIN_ADS7953_1);
    ADS7953_1.setClockDivider(SPI_CLOCK_DIV16);
    ADS7953_1.setDataMode(SPI_MODE0); // ADS7953 uses SPI Mode 0
    ADS7953_1.setBitOrder(MSBFIRST);  // ADS7953 expects MSB first
    setupADS7953(ADS7953_1, CS_PIN_ADS7953_1);

    ADS7953_2.begin();
    ADS7953_2.setMOSI(MOSI_PIN_ADS7953_2);
    ADS7953_2.setMISO(MISO_PIN_ADS7953_2);
    ADS7953_2.setSCLK(SCK_PIN_ADS7953_2);
    ADS7953_2.setClockDivider(SPI_CLOCK_DIV16);
    ADS7953_2.setDataMode(SPI_MODE0); // ADS7953 uses SPI Mode 0
    ADS7953_2.setBitOrder(MSBFIRST);  // ADS7953 expects MSB first
    setupADS7953(ADS7953_2, CS_PIN_ADS7953_2);

    ADS7953_3.begin();
    ADS7953_3.setDataMode(SPI_MODE0); // ADS7953 uses SPI Mode 0
    ADS7953_3.setBitOrder(MSBFIRST);  // ADS7953 expects MSB first
    setupSoftADS7953(ADS7953_3, CS_PIN_ADS7953_3);
}

void loop()
{
    if (Serial.available() > 0)
    {
        char command = Serial.read();
        if (command == 'a')
        {
            readADS7953(ADS7953_1, 0, CS_PIN_ADS7953_1);
            readADS7953(ADS7953_2, 2, CS_PIN_ADS7953_2);
            readSoftADS7953(ADS7953_3, 1, CS_PIN_ADS7953_3);
            printADC();
        }
        else if (command == 'd')
        {
            JumpToBootloader();
        } else if (command == 'r')
        {
            reset();
        }
    }
}

void setupADS7953(SPIClass ADS7953, int cs)
{
    pinMode(cs, OUTPUT);
    digitalWrite(cs, HIGH);

    // Reset the device
    digitalWrite(cs, LOW);
    ADS7953.transfer16(0x4200);
    digitalWrite(cs, HIGH);

    // Set the device to Auto mode 2
    digitalWrite(cs, LOW);
    ADS7953.transfer16(0x3C40);
    digitalWrite(cs, HIGH);

    // Set last channel to be read to 15
    digitalWrite(cs, LOW);
    ADS7953.transfer16(0x93C0);
    digitalWrite(cs, HIGH);
}

void setupSoftADS7953(SoftSPI ADS7953, int cs)
{
    pinMode(cs, OUTPUT);
    digitalWrite(cs, HIGH);

    // Reset the device
    digitalWrite(cs, LOW);
    ADS7953.transfer16(0x4200);
    digitalWrite(cs, HIGH);

    // Set the device to Auto mode 2
    digitalWrite(cs, LOW);
    ADS7953.transfer16(0x3C40);
    digitalWrite(cs, HIGH);

    // Set last channel to be read to 15
    digitalWrite(cs, LOW);
    ADS7953.transfer16(0x93C0);
    digitalWrite(cs, HIGH);
}

void readADS7953(SPIClass ADS7953, int adc, int cs)
{
    for (int i = 0; i < 16; i++)
    {
        digitalWrite(cs, LOW);
        uint16_t rawData = ADS7953.transfer16(0x0000);
        digitalWrite(cs, HIGH);

        uint16_t channel = (rawData & 0xF000) >> 12;
        channel = (channel + adc * 16);
        uint16_t adcValue = rawData & 0x0FFF;
        sensorData[channel] = adcValue;
    }
}

void readSoftADS7953(SoftSPI ADS7953, int adc, int cs)
{
    for (int i = 0; i < 16; i++)
    {
        digitalWrite(cs, LOW);
        uint16_t rawData = ADS7953.transfer16(0x0000);
        digitalWrite(cs, HIGH);

        uint16_t channel = (rawData & 0xF000) >> 12;
        channel = (channel + adc * 16);
        uint16_t adcValue = rawData & 0x0FFF;
        sensorData[channel] = adcValue;
    }
}

void printADC()
{
    for (int row = 0; row < 8; row++) // Columns 1-6
    {
        for (int col = 0; col < 6; col++) // Rows A-H
        {
            int index = col * 6 + row; // Corrected the indexing logic
            char buffer[4];
            Serial.print((char)('A' + row)); // Print row letter
            Serial.print(col + 1);          // Print column number
            Serial.print("_");
            sprintf(buffer, "%04d", sensorData[order[index]]);
            Serial.print(buffer);
            if (index < CHANNELS_TO_PRINT - 1)
            {
                Serial.print("_");
            }
            else
            {
                Serial.println();
            }
        }
    }
    // for (int i = 0; i < CHANNELS_TO_PRINT; i++)
    // {
    //     char buffer[4];
    //     Serial.print("A");
    //     Serial.print(i);
    //     Serial.print("_");
    //     sprintf(buffer, "%04d", sensorData[order[i]]);
    //     Serial.print(buffer);
    //     if (i < CHANNELS_TO_PRINT - 1)
    //     {
    //         Serial.print("_");
    //     }
    //     else
    //     {
    //         Serial.println();
    //     }
    // }
}

void reset()
{
    NVIC_SystemReset();
}

#define BOOT_ADDR 0x1FFFC800

struct boot_vectable_
{
    uint32_t Initial_SP;
    void (*Reset_Handler)(void);
};

#define BOOTVTAB ((struct boot_vectable_ *)BOOT_ADDR)

void JumpToBootloader(void)
{
    __disable_irq();

    USB->CNTR = 0x0003;

    SysTick->CTRL = 0;

    HAL_RCC_DeInit();

    for (int i = 0; i < sizeof(NVIC->ICER) / sizeof(NVIC->ICER[0]); i++)
    {
        NVIC->ICER[i] = 0xFFFFFFFF;
        NVIC->ICPR[i] = 0xFFFFFFFF;
    }

    __enable_irq();

    __set_MSP(BOOTVTAB->Initial_SP);

    BOOTVTAB->Reset_Handler();
}

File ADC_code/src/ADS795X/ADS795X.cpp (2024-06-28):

#include "ADS795X.h"

#define HIGH_BYTE                                   (0xFF00)
#define LOW_BYTE                                    (0x00FF)


#define CMD_AUTO1_PROGRAMMING_SEQUENCE              (1 << 15)
#define CMD_AUTO2_PROGRAMMING_SEQUENCE              ((1 << 15) | (1 << 12))

ADS795X::ADS795X()
{
    // Constructor
    auto1_active_channels = 0x00;
    auto2_last_channel_address = 0x00;
    slave_select_pin = -1;
}

void ADS795X::enterProgramSequenceAuto1(void)
{
    _spiPort->beginTransaction(SPISettings(_spiClock, _spiBitOrder, _spiDataMode));

    digitalWrite(slave_select_pin, LOW);

    _spiPort->transfer((uint8_t) (CMD_AUTO1_PROGRAMMING_SEQUENCE & HIGH_BYTE));

    _spiPort->transfer((uint8_t) (CMD_AUTO1_PROGRAMMING_SEQUENCE & LOW_BYTE));

    _spiPort->transfer((uint8_t) (auto1_active_channels & HIGH_BYTE));
    
    _spiPort->transfer((uint8_t) (auto1_active_channels & LOW_BYTE));

    digitalWrite(slave_select_pin, HIGH);

    _spiPort->endTransaction();
}

void ADS795X::enterProgramSequenceAuto2(void)
{
    uint32_t cmd = (CMD_AUTO2_PROGRAMMING_SEQUENCE | (auto2_last_channel_address << 6));
    _spiPort->beginTransaction(SPISettings(_spiClock, _spiBitOrder, _spiDataMode));

    digitalWrite(slave_select_pin, LOW);

    _spiPort->transfer((uint8_t) (cmd & HIGH_BYTE));

    _spiPort->transfer((uint8_t) (cmd & LOW_BYTE));

    digitalWrite(slave_select_pin, HIGH);

    _spiPort->endTransaction();
}

boolean ADS795X::initCommunication(SPIClass &spiPort, uint32_t clock, uint8_t bitOrder, uint8_t dataMode)
{
    boolean statusCode = false;

    if(slave_select_pin == -1)
    {
        goto exit;
    }

    operationMode = MANUAL_MODE;

    _spiPort = &spiPort;
    _spiClock = clock;
    _spiBitOrder = bitOrder;
    _spiDataMode = dataMode;
    
    digitalWrite(slave_select_pin, HIGH);

    _spiPort->begin();

    if(auto1_active_channels != 0x00)
    {
        enterProgramSequenceAuto1();
    }

    if(auto2_last_channel_address != 0x00)
    {
        enterProgramSequenceAuto2();
    }

    statusCode = true;

exit:

    return statusCode;
}


void ADS795X::setFunctionalMode(controlRegisterMode regValue)
{
    _spiPort->beginTransaction(SPISettings(_spiClock, _spiBitOrder, _spiDataMode));
    
    digitalWrite(slave_select_pin, LOW);

    _spiPort->transfer((uint8_t) (regValue.cmd & HIGH_BYTE));

    _spiPort->transfer((uint8_t) (regValue.cmd & LOW_BYTE));

    digitalWrite(slave_select_pin, HIGH);

    _spiPort->endTransaction();

    operationMode = (uint8_t)(regValue.cmd >> 12);;
}

uint16_t ADS795X::readData(uint8_t channel)
{
    uint16_t data_rx;
    controlRegisterMode regValue;

    regValue.cmd = operationMode << 12;

    if(operationMode == MANUAL_MODE)
    {
        regValue.bit_access_manual.enable_programming = 0x00;
        regValue.bit_access_manual.next_channel = channel & 0x0F;
    }
    else if((operationMode == AUTO1_MODE) || (operationMode == AUTO2_MODE))
    {
        regValue.bit_access_auto.enable_programming = 0x00;
        regValue.bit_access_auto.reset_counter = 0x00;
    }
    else
    {
        regValue.cmd = (uint16_t) 0x00;
    }

    _spiPort->beginTransaction(SPISettings(_spiClock, _spiBitOrder, _spiDataMode));
    
    digitalWrite(slave_select_pin, LOW);

    data_rx = _spiPort->transfer((uint8_t) (regValue.cmd & HIGH_BYTE));

    data_rx |= _spiPort->transfer((uint8_t) (regValue.cmd & LOW_BYTE)) << 8;

    digitalWrite(slave_select_pin, HIGH);

    _spiPort->endTransaction();

    return data_rx;
}

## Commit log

2024-06-28 uploaded based code and pcb
    [ADC.kicad_pcb, ADC.kicad_sch]
2024-07-04 added SPI code
2024-07-25 updated schematic to match the eval kit
    [ADC.kicad_pcb, ADC.kicad_sch]
2024-07-26 finished V2
    [ADC.kicad_pcb, ADC.kicad_sch]
2024-07-29 updated v2
    [ADC.kicad_pcb, ADC.kicad_sch]
2024-07-29 updated gerbers
2024-09-17 updated code
    [ADC.kicad_sch]
2024-10-04 float print
2024-11-15 pcb update
    [ADC.kicad_pcb, ADC.kicad_sch]
2025-05-16 added remote dfu and reset
    [main.cpp]
